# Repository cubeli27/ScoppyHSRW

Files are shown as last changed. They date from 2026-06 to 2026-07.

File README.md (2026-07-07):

# Scoppy 

## Overview
Scoppy is an hardware extension project designed to be compatible with the [original Scopy Project](https://github.com/fhdm-dev/scoppy) developed by fhdm-dev. This repository extends the original Raspberry Pi Pico oscilloscope software by providing custom hardware developed as teaching material for the course Design and Manufacturing of Electronics.

The hardware platform enables students to study and manufacture a complete measurement instrument while using the original Scoppy firmware.

<!-- To-do: Add more photos to the list -->
<p align="center"> 
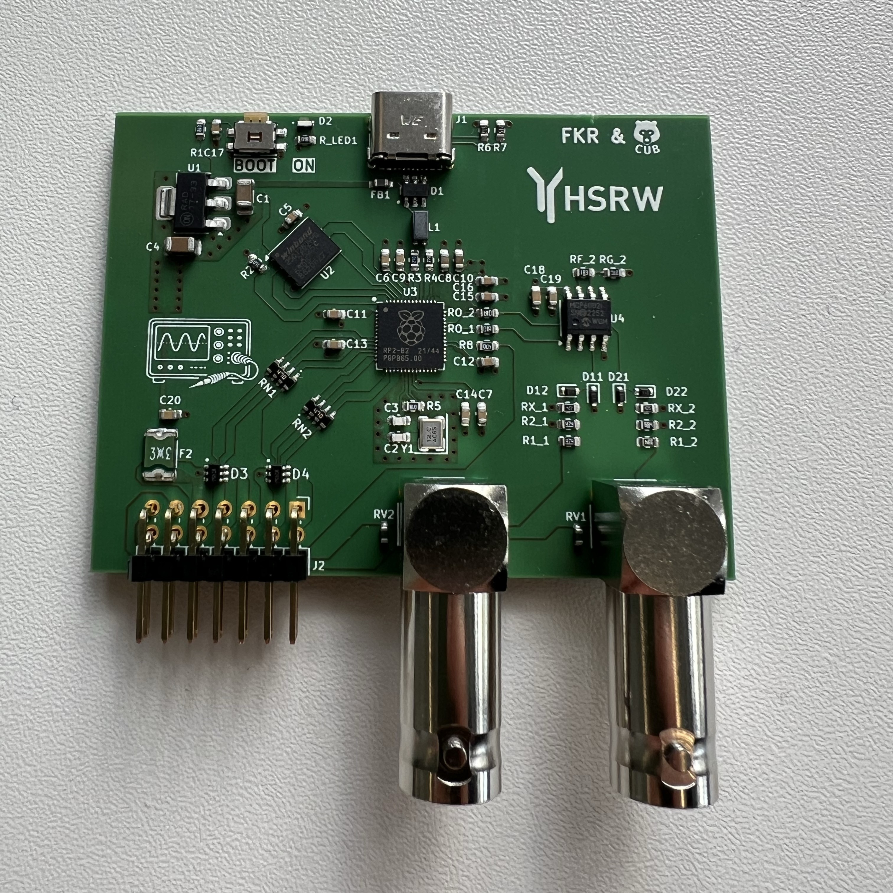
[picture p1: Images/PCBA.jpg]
PCBA
   
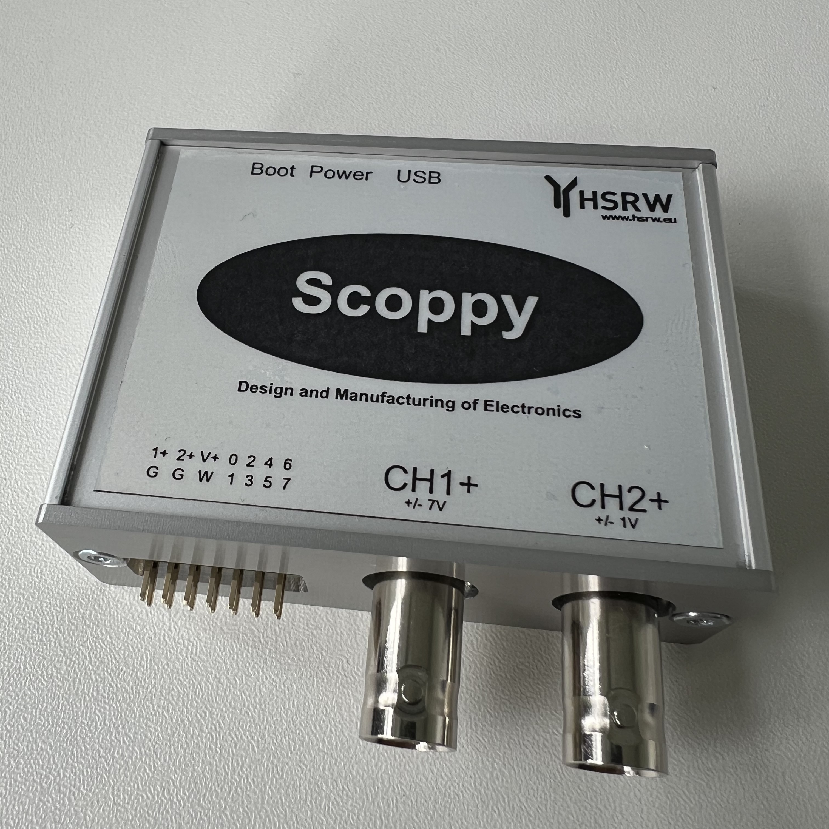
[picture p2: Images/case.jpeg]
   
</p> 

Key Features
- Oscilloscope
- Logic analyzer
- Function generator

---

## Project Structure

| Folder | Description | Contents |
|---|---|---|
| **CAD_files** | Case drawings and pcb | .pdf and .step |
| **ECAD_files** | Contains PCB files | Original design and student template  |
| **Images** | Report relevant snippets | Images |
| **Waveforms** | Waveforms Testing Workspace | .dwf3work |

---

## Testing

Images of Scoppy in action.
<p align="center"> 
  PCBA 
  PCBA 
</p>  

---
## Firmware

Original project can be found at:<br>
[Github](https://github.com/fhdm-dev/scoppy)<br>
[EasyEDA](https://easyeda.com/editor#id=5d5f637d6a8448b59f484372ed679191)<br>
[Website](https://oscilloscope.fhdm.xyz/)  
 
---
## Getting Started

From the [Scoppy Firmware downloads](https://oscilloscope.fhdm.xyz/wiki/firmware-versions) download and flash the **scoppy-pico-v18.uf2** .

---
## Future Work 
C17 capacitor can be omited or not populated. It is the boot push-button debounce capacitor and in some layouts prevents proper booting persumably because the **RUN** pin is left floating so the code starts running while the capacitor is still charging and before **BOOT** pin reaches logic high. 

---
## Acknowledgements

This project would not have been possible without the original Scoppy software created by the fhdm-dev team. Their work provided the foundation that made this hardware implementation possible.
---
## Author

Developed by **cubeli27** with the support of Frank Kremer (FKR)
For questions or collaboration, feel free to reach out. See my contact info in the [profile repo](https://github.com/cubeli27/cubeli27).

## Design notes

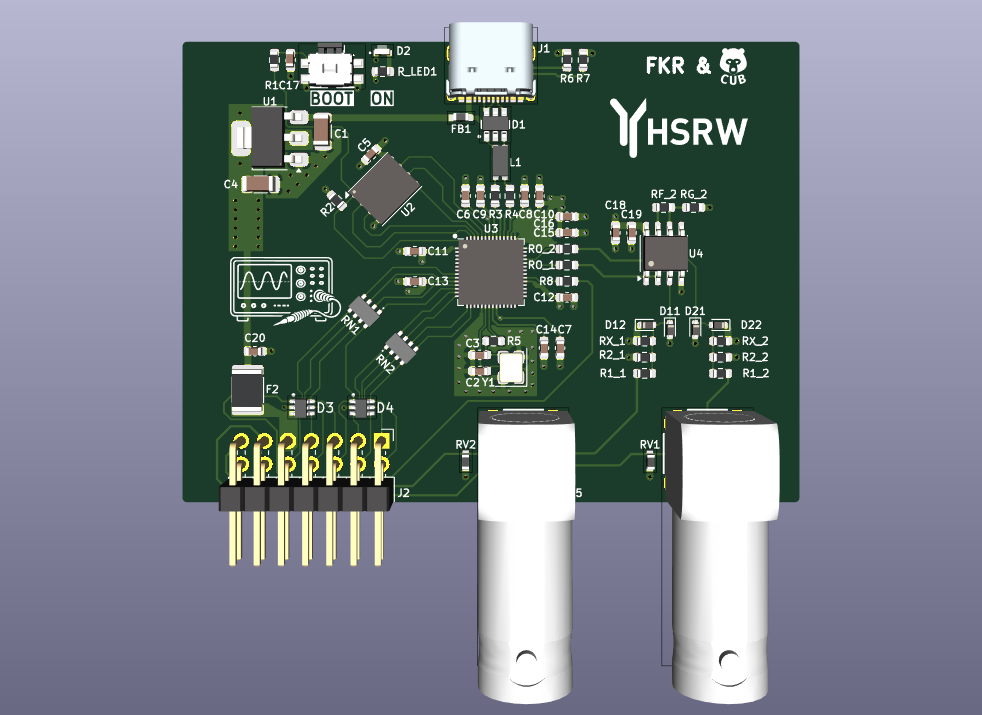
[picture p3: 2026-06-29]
Images/3D Viewer.png

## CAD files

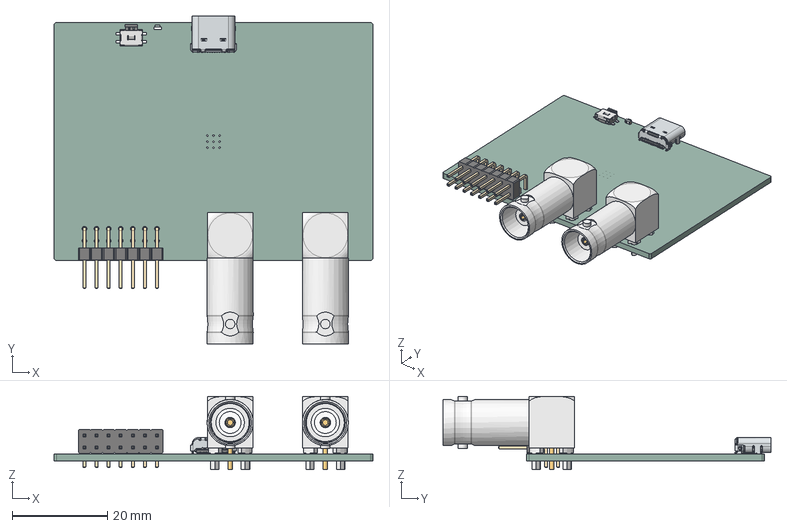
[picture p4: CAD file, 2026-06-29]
CAD_files/scoppy.step
67.0 x 68.9 x 15.4 mm
629722000214_Housing
629722000214_Pin1_Top
629722000214_Pin4_Bottom
629722000214_Pin4_Top x 2
629722000214_Pin1_Bottom
629722000214_Pin3_Bottom
629722000214_Pin3_Top
629722000214_Pin2_Top
629722000214_Pin2_Bottom
629722000214_Pin1_Top_mir
629722000214_Pin1_Bottom_mir
629722000214_Pin2_Top_mir
629722000214_Pin2_Bottom_mir
629722000214_Pin3_Top_mir
629722000214_Pin3_Bottom_mir
629722000214_Pin4_Bottom_mir
629722000214_Shielding2
629722000214_Shielding
PinHeader_2x07_P2.54mm_Horizontal
60711002241501_Body x 2
60711002241501_Cover x 2
60711002241501_housing x 2
60711002241501_insulator x 2
60711002241501_insulator_2 x 2
60711002241501_Lok_Ring x 2
60711002241501_Pin x 2
60711002241501_Pin_2 x 2
frame
pins x 4
stem
cover
Pins
Dome
scoppy_PCB

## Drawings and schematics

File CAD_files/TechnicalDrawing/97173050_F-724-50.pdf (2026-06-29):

5

8

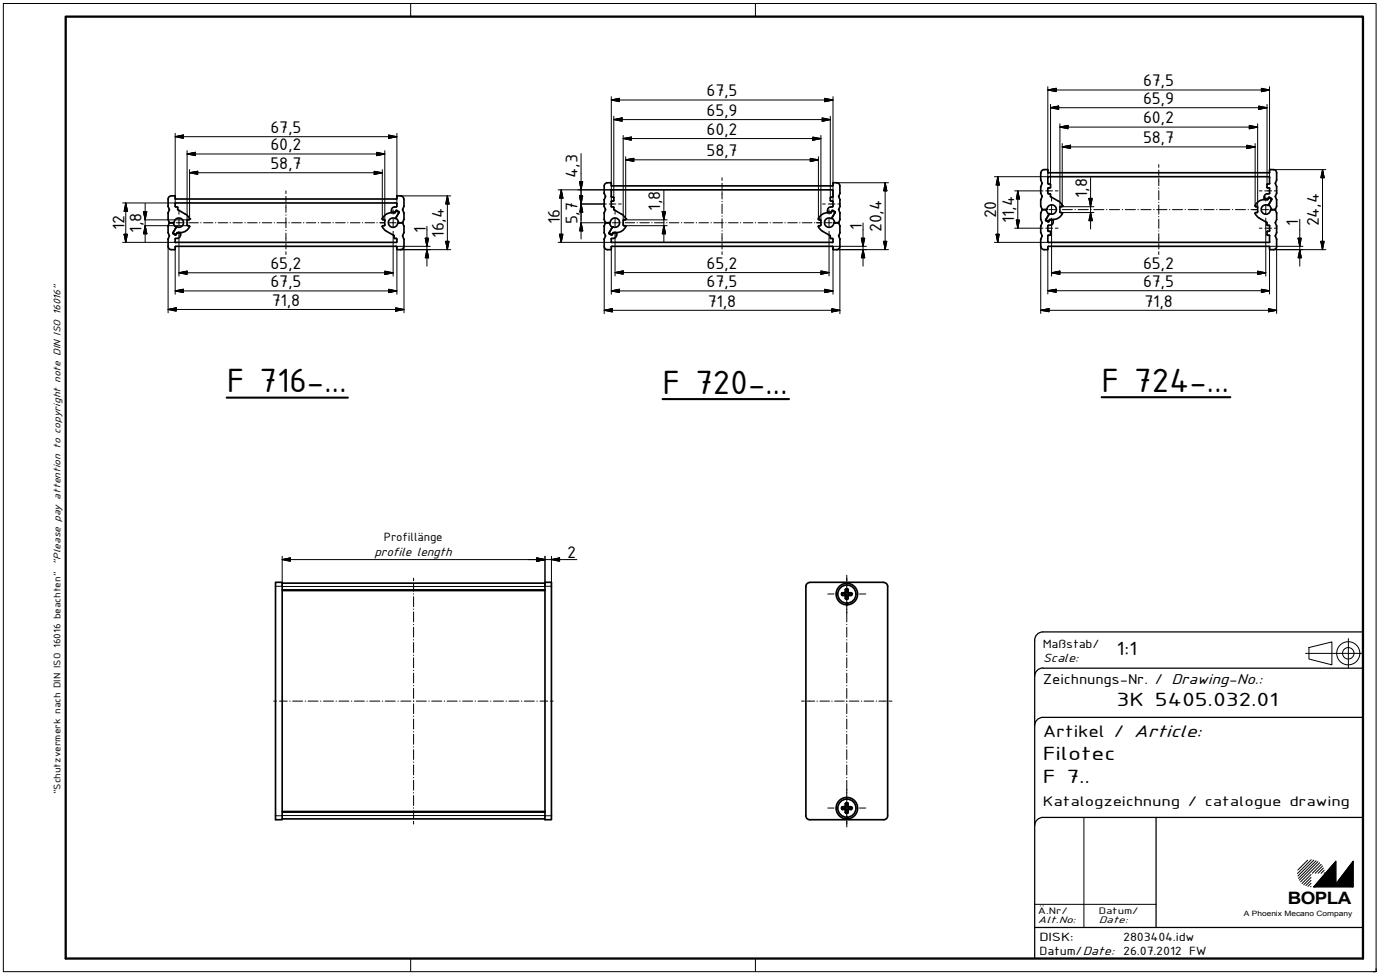
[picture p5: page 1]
tik; DIS; K: Filo; eic; 7.. Katalo; win; fil

"Schutzvermerk nach DIN ISO 16016 beachten" "Please pay attention to copyright note DIN ISO 16016"

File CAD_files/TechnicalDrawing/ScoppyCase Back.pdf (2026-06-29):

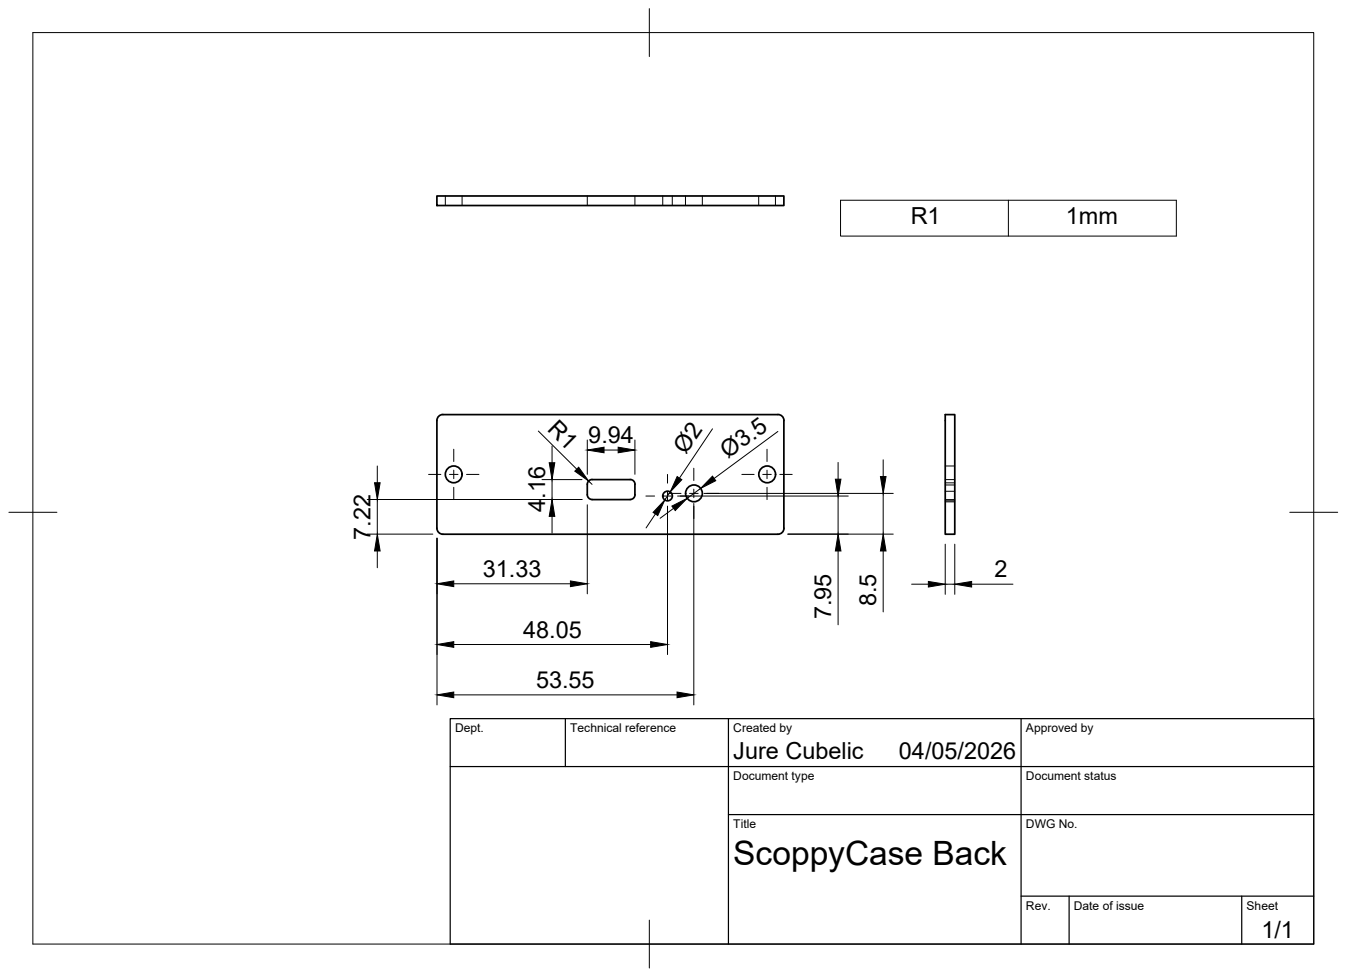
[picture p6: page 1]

Dept. | Technical reference | Created by Jure Cubelic 04/05/2026 | Approved by

Document type | Document status

Title ScoppyCase Back | DWG No.

Rev. | Date of issue | Sheet 1/1

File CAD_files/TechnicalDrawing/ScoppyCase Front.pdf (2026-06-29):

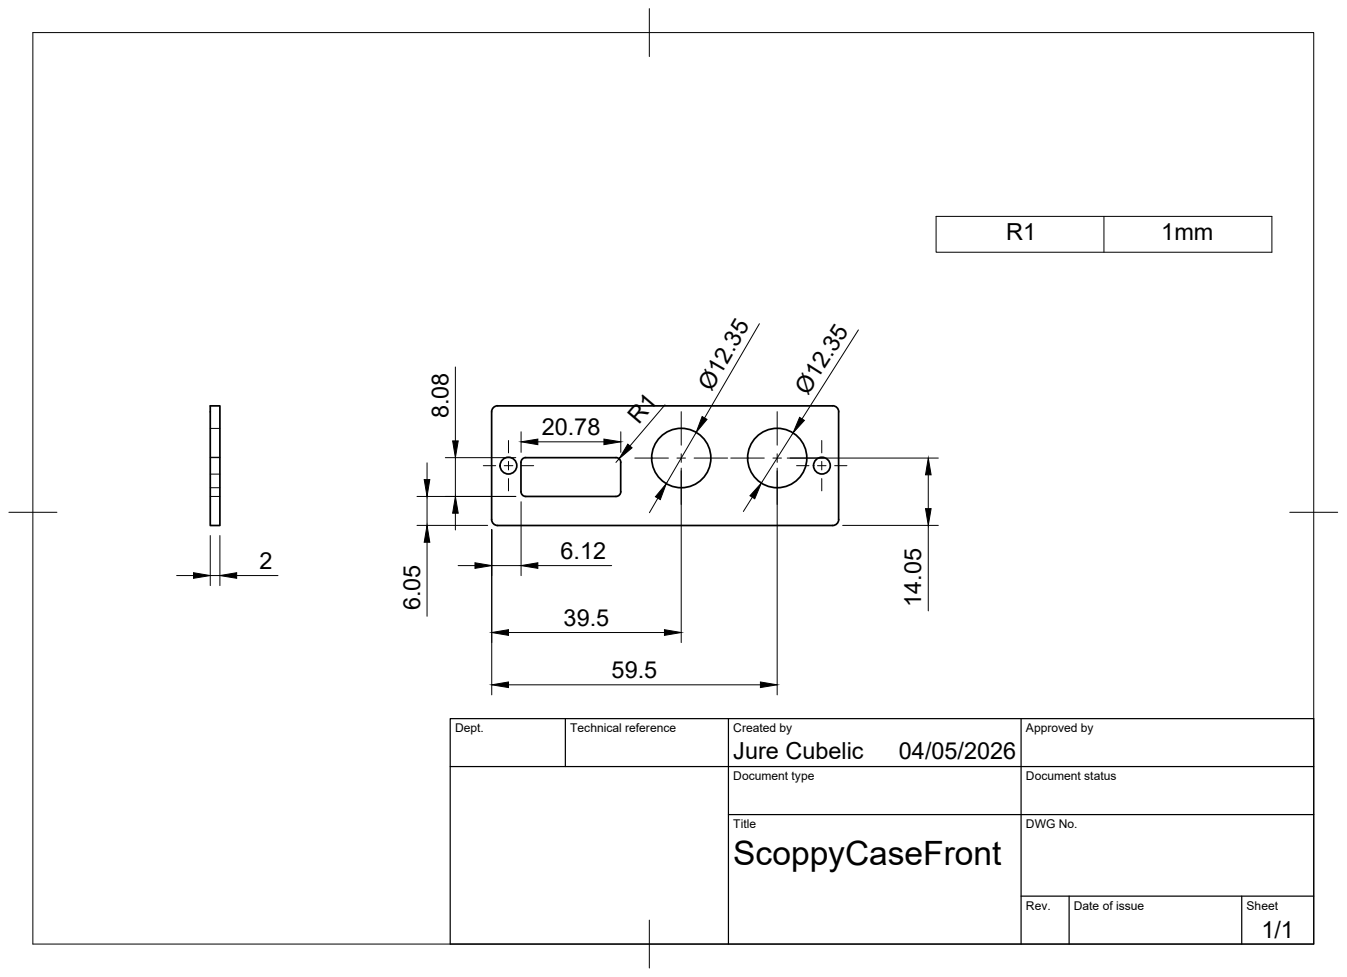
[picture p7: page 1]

Dept. | Technical reference | Created by Jure Cubelic 04/05/2026 | Approved by

Document type | Document status

Title ScoppyCaseFront | DWG No.

Rev. | Date of issue | Sheet 1/1

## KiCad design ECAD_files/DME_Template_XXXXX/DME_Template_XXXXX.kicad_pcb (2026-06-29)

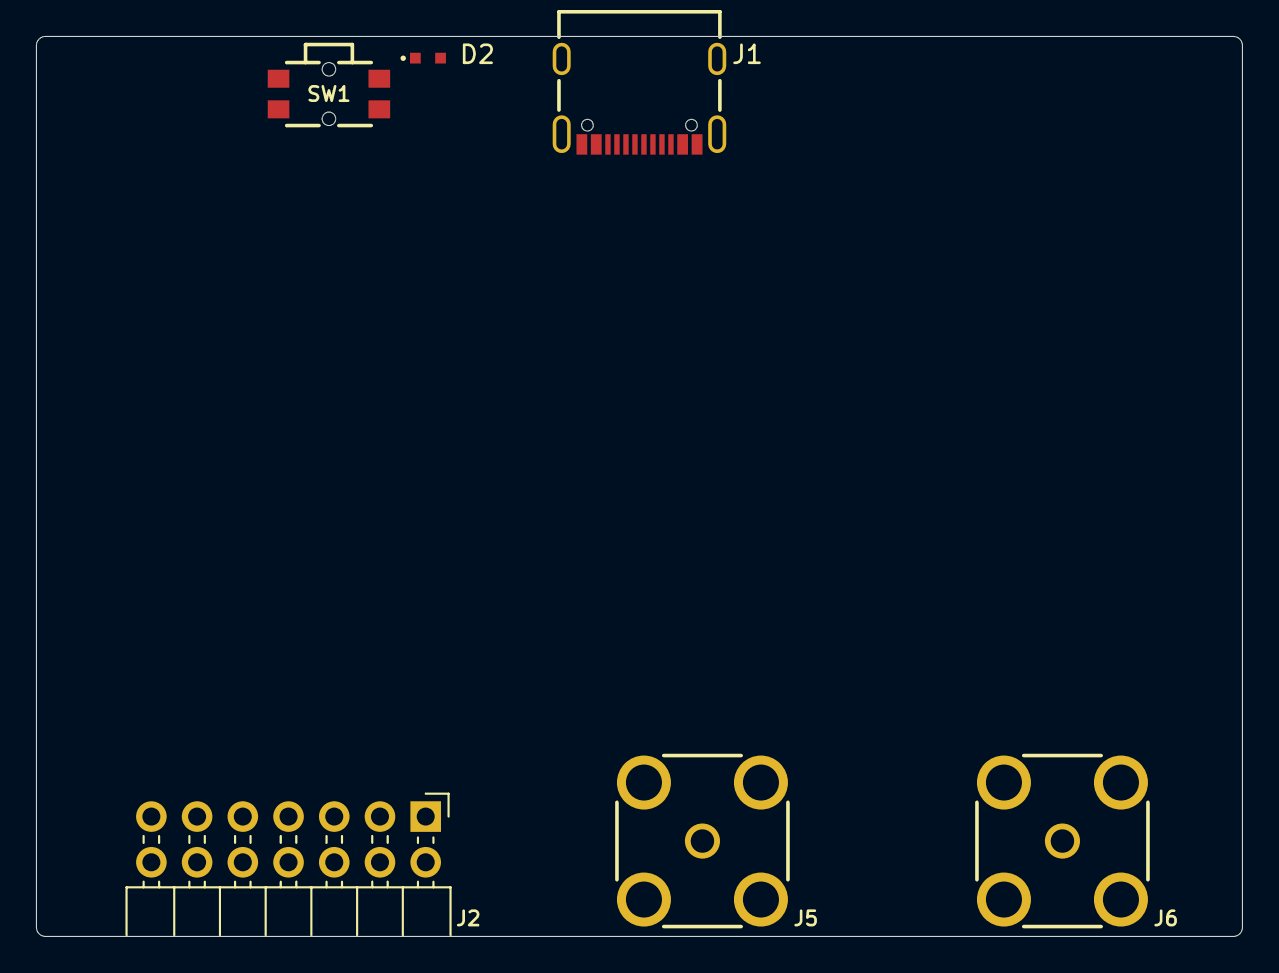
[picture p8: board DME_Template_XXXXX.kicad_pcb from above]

Board: 4 copper layers, 67.0 x 50.0 mm, 6 parts (0 on the bottom side), 7 nets, no tracks yet.

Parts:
D2: Bright Green, 2V, 140°; WL-SMSW_0603_L1.6W0.98H0.8
J1: 629722000214
J2: Conn_02x07_Odd_Even; PinHeader_2x07_P2.54mm_Horizontal
J5, J6: 60711002241501
SW1: 436351045816

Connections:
/Analog/CH1+: J2.13, J5.1 (Signal)
/Analog/CH2+: J2.11, J6.1 (Signal)
/Digital/~USB_BOOT: SW1.B1, SW1.B2
/Power/unprotectedD+: J1.A6 (D+1), J1.B6 (D+2)
/Power/unprotectedD-: J1.A7 (D-1), J1.B7 (D-2)
GND: D2.1 (K), J1.A1/B12 (GND), J1.A12/B1 (GND), J1.Shell (Shield), J2.12, J2.14, J5.2 (GND), J5.3 (GND), J5.4 (GND), J5.5 (GND), J6.2 (GND), J6.3 (GND), J6.4 (GND), J6.5 (GND), SW1.A1, SW1.A2
VBUS: J1.A4/B9 (VBUS), J1.A9/B4 (VBUS)

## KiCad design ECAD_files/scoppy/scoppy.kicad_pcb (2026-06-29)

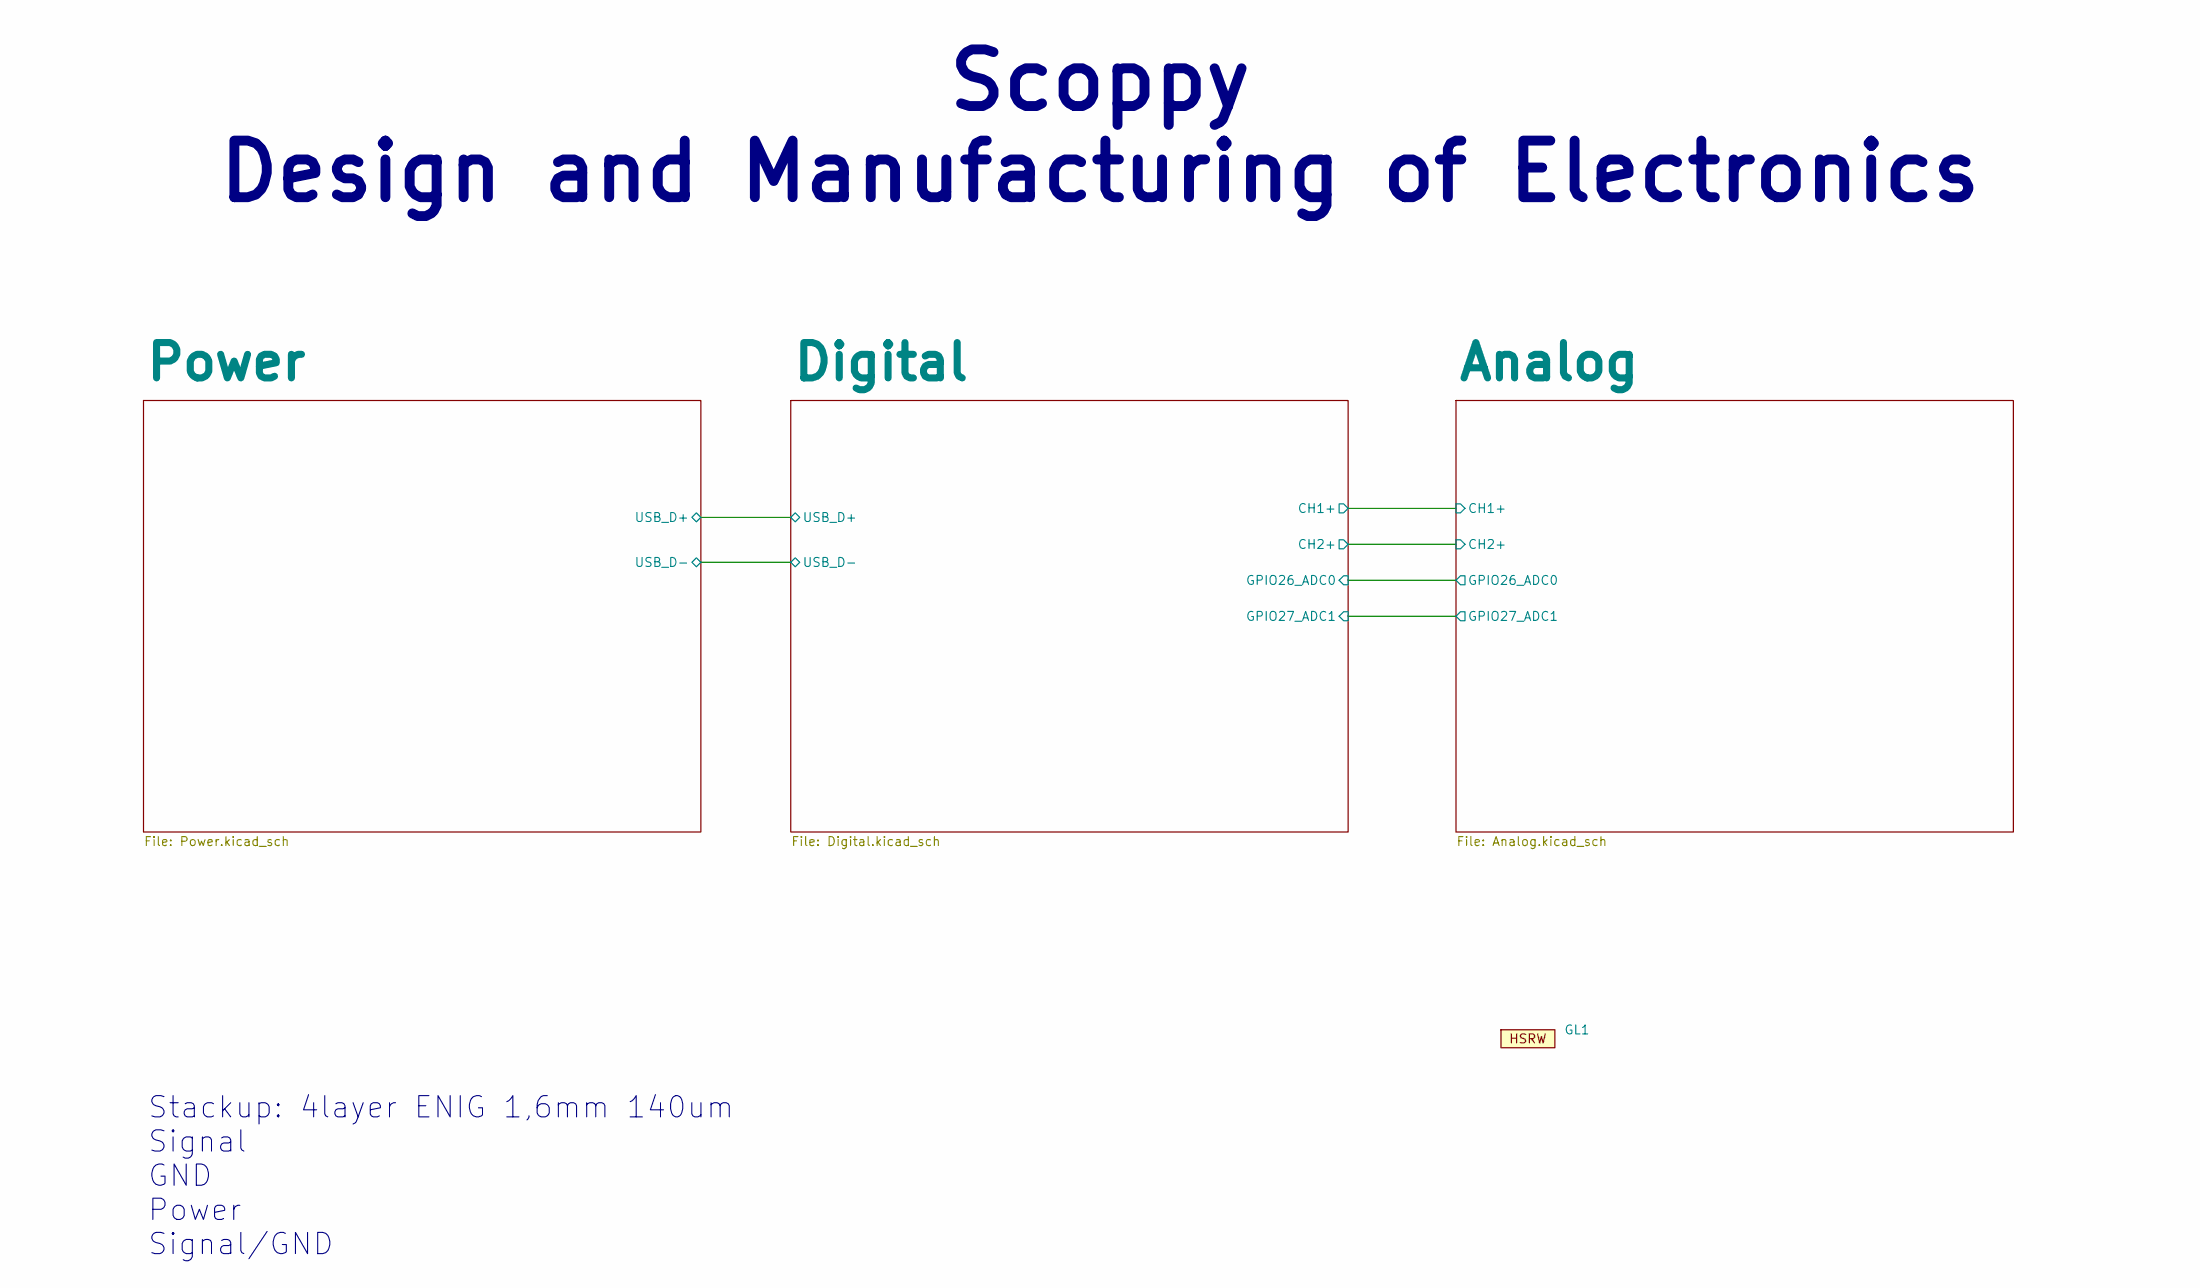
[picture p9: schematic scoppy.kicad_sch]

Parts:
GL1: hsrw

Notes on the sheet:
Stackup: 4layer ENIG 1,6mm 140um Signal GND Power Signal/GND
Scoppy Design and Manufacturing of Electronics

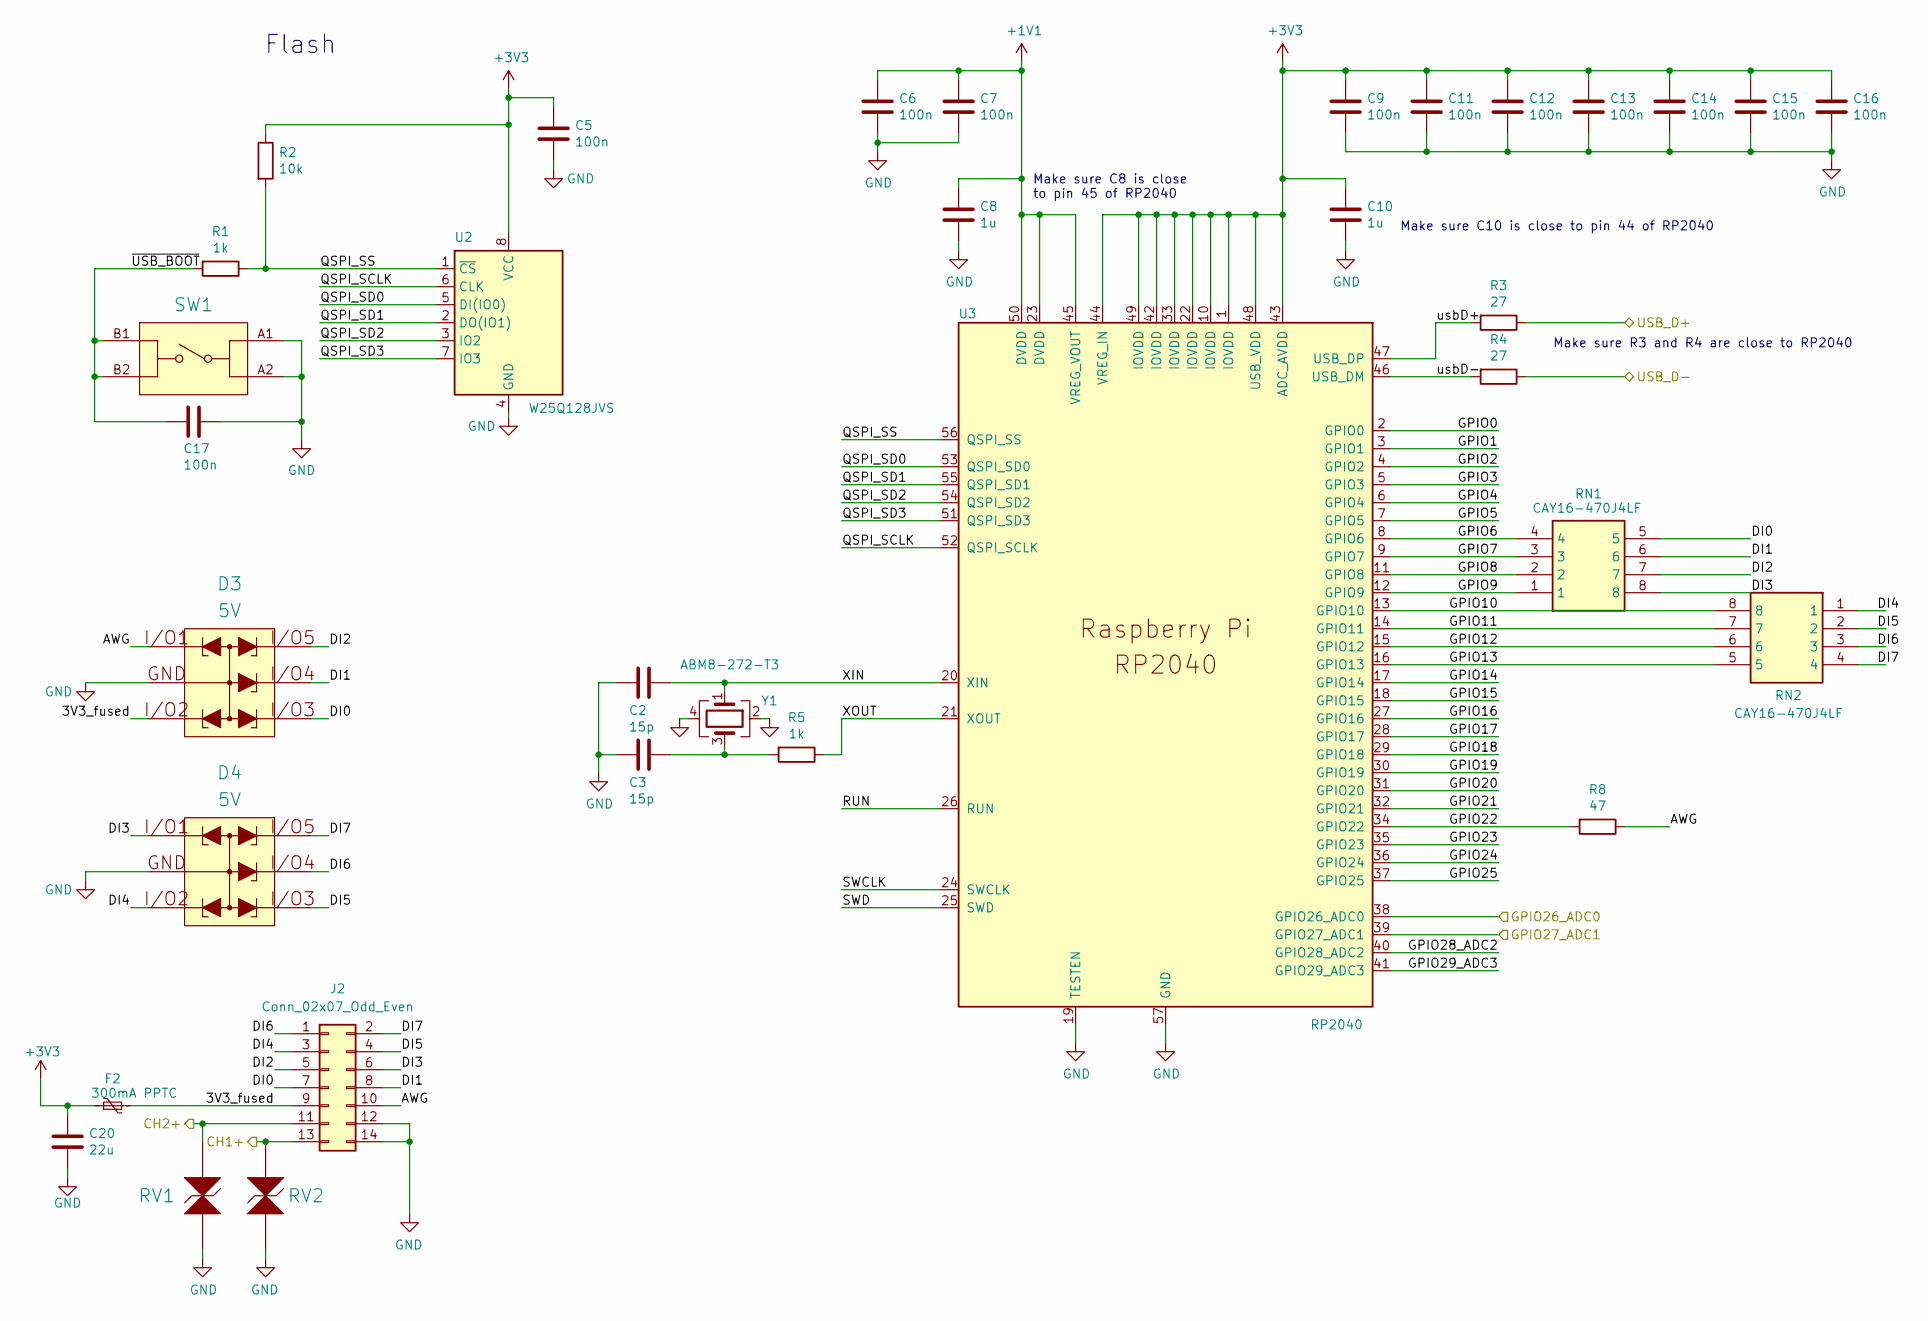
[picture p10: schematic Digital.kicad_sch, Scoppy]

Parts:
C2, C3: 15p; C_0603_1608Metric
C5, C6, C7, C9, C11, C12, C13, C14, C15, C16, C17: 100n; C_0603_1608Metric
C8, C10: 1u; C_0603_1608Metric
C20: 22u; C_0603_1608Metric
D3, D4: 5V; WE-TVS_SC70-6L; Manufacturer Part Number 82402375
F2: 300mA PPTC; Fuse_1812_4532Metric
J2: Conn_02x07_Odd_Even; PinHeader_2x07_P2.54mm_Horizontal
R1, R5: 1k; R_0603_1608Metric
R2: 10k; R_0603_1608Metric
R3, R4: 27; R_0603_1608Metric
R8: 47; R_0603_1608Metric
RN1, RN2: CAY16-470J4LF; CAY16470J4LF; Mouser Part Number 652-CAY16-470J4LF
RV1, RV2: 12VDC, 5pF; WE-VE_0603; Clamping Voltage 80V; ESD Voltage 15kV; Manufacturer Part Number 82356120050
SW1: 436351045816; Rated Voltage 12VDC; Manufacturer Part Number 436351045816
U2: W25Q128JVS; WSON-8-1EP_6x5mm_P1.27mm_EP3.4x4.3mm
U3: RP2040; RP2040-QFN-56
Y1: ABM8-272-T3; Crystal_SMD_3225-4Pin_3.2x2.5mm

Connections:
+1V1: C6.1, C7.1, C8.1, U3.23 (DVDD), U3.45 (VREG_VOUT), U3.50 (DVDD)
+3V3: C5.1, C9.1, C10.1, C11.1, C12.1, C13.1, C14.1, C15.1, C16.1, C20.1, F2.2, R2.1, U2.8 (VCC), U3.1 (IOVDD), U3.10 (IOVDD), U3.22 (IOVDD), U3.33 (IOVDD), U3.42 (IOVDD), U3.43 (ADC_AVDD), U3.44 (VREG_IN), U3.48 (USB_VDD), U3.49 (IOVDD); also elsewhere on the board
/Analog/CH1+: J2.13, RV2.2; also elsewhere on the board
/Analog/CH2+: J2.11, RV1.2; also elsewhere on the board
/Analog/GPIO26_ADC0: U3.38 (GPIO26_ADC0); also elsewhere on the board
/Analog/GPIO27_ADC1: U3.39 (GPIO27_ADC1); also elsewhere on the board
/Digital/3V3_fused: D3.3 (I/O_2), F2.1, J2.9
/Digital/AWG: D3.1 (I/O_1), J2.10, R8.1
/Digital/DI0: D3.4 (I/O_3), J2.7, RN1.5
/Digital/DI1: D3.5 (I/O_4), J2.8, RN1.6
/Digital/DI2: D3.6 (I/O_5), J2.5, RN1.7
/Digital/DI3: D4.1 (I/O_1), J2.6, RN1.8
/Digital/DI4: D4.3 (I/O_2), J2.3, RN2.1
/Digital/DI5: D4.4 (I/O_3), J2.4, RN2.2
/Digital/DI6: D4.5 (I/O_4), J2.1, RN2.3
/Digital/DI7: D4.6 (I/O_5), J2.2, RN2.4
/Digital/GPIO0: U3.2 (GPIO0)
/Digital/GPIO1: U3.3 (GPIO1)
/Digital/GPIO2: U3.4 (GPIO2)
/Digital/GPIO3: U3.5 (GPIO3)
/Digital/GPIO4: U3.6 (GPIO4)
/Digital/GPIO5: U3.7 (GPIO5)
/Digital/GPIO6: RN1.4, U3.8 (GPIO6)
/Digital/GPIO7: RN1.3, U3.9 (GPIO7)
/Digital/GPIO8: RN1.2, U3.11 (GPIO8)
/Digital/GPIO9: RN1.1, U3.12 (GPIO9)
/Digital/GPIO10: RN2.8, U3.13 (GPIO10)
/Digital/GPIO11: RN2.7, U3.14 (GPIO11)
/Digital/GPIO12: RN2.6, U3.15 (GPIO12)
/Digital/GPIO13: RN2.5, U3.16 (GPIO13)
/Digital/GPIO14: U3.17 (GPIO14)
/Digital/GPIO15: U3.18 (GPIO15)
/Digital/GPIO16: U3.27 (GPIO16)
/Digital/GPIO17: U3.28 (GPIO17)
/Digital/GPIO18: U3.29 (GPIO18)
/Digital/GPIO19: U3.30 (GPIO19)
/Digital/GPIO20: U3.31 (GPIO20)
/Digital/GPIO21: U3.32 (GPIO21)
/Digital/GPIO22: R8.2, U3.34 (GPIO22)
/Digital/GPIO23: U3.35 (GPIO23)
/Digital/GPIO24: U3.36 (GPIO24)
/Digital/GPIO25: U3.37 (GPIO25)
/Digital/GPIO28_ADC2: U3.40 (GPIO28_ADC2)
/Digital/GPIO29_ADC3: U3.41 (GPIO29_ADC3)
/Digital/QSPI_SCLK: U2.6 (CLK), U3.52 (QSPI_SCLK)
/Digital/QSPI_SD0: U2.5 (DI(IO0)), U3.53 (QSPI_SD0)
/Digital/QSPI_SD1: U2.2 (DO(IO1)), U3.55 (QSPI_SD1)
/Digital/QSPI_SD2: U2.3 (IO2), U3.54 (QSPI_SD2)
/Digital/QSPI_SD3: U2.7 (IO3), U3.51 (QSPI_SD3)
/Digital/QSPI_SS: R1.1, R2.2, U2.1 (~CS), U3.56 (QSPI_SS)
/Digital/RUN: U3.26 (RUN)
/Digital/SWCLK: U3.24 (SWCLK)
/Digital/SWD: U3.25 (SWD)
/Digital/USB_D+: R3.1; also elsewhere on the board
/Digital/USB_D-: R4.1; also elsewhere on the board
/Digital/XIN: C2.1, U3.20 (XIN), Y1.1
/Digital/XOUT: R5.1, U3.21 (XOUT)
/Digital/usbD+: R3.2, U3.47 (USB_DP)
/Digital/usbD-: R4.2, U3.46 (USB_DM)
/Digital/~USB_BOOT: C17.1, R1.2, SW1.B1, SW1.B2
GND: C2.2, C3.2, C5.2, C6.2, C7.2, C8.2, C9.2, C10.2, C11.2, C12.2, C13.2, C14.2, C15.2, C16.2, C17.2, C20.2, D3.2 (GND), D4.2 (GND), J2.12, J2.14, RV1.1, RV2.1, SW1.A1, SW1.A2, U2.4 (GND), U3.19 (TESTEN), U3.57 (GND), Y1.2, Y1.4; also elsewhere on the board
unnamed: C3.1, R5.2, Y1.3

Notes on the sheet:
Make sure C8 is close to pin 45 of RP2040
Flash
Make sure R3 and R4 are close to RP2040
Make sure C10 is close to pin 44 of RP2040

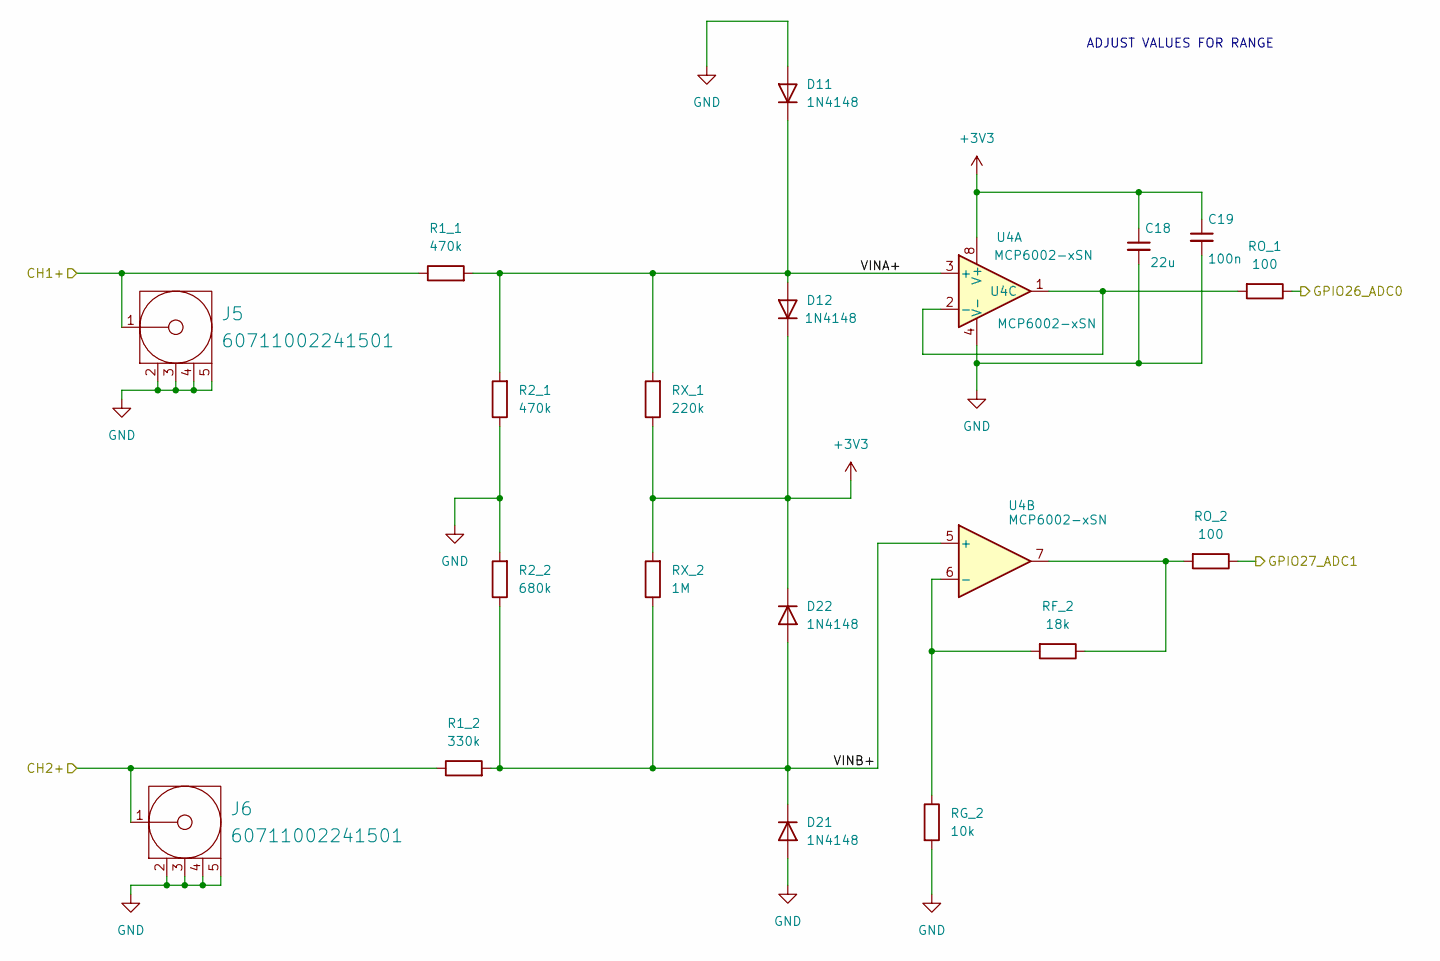
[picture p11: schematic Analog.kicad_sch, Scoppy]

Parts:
C18: 22u; C_0603_1608Metric
C19: 100n; C_0603_1608Metric
D11, D12, D21, D22: 1N4148; D_SOD-523
J5, J6: 60711002241501; Manufacturer Part Number 60711002241501
R1_1, R2_1: 470k; R_0603_1608Metric
R1_2: 330k; R_0603_1608Metric
R2_2: 680k; R_0603_1608Metric
RF_2: 18k; R_0603_1608Metric
RG_2: 10k; R_0603_1608Metric
RO_1, RO_2: 100; R_0603_1608Metric
RX_1: 220k; R_0603_1608Metric
RX_2: 1M; R_0603_1608Metric
U4: MCP6002-xSN; SOIC-8_3.9x4.9mm_P1.27mm

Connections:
+3V3: C18.1, C19.1, D12.1 (K), D22.1 (K), RX_1.1, RX_2.2, U4.8 (V+); also elsewhere on the board
/Analog/CH1+: J5.1 (Signal), R1_1.1; also elsewhere on the board
/Analog/CH2+: J6.1 (Signal), R1_2.1; also elsewhere on the board
/Analog/GPIO26_ADC0: RO_1.1; also elsewhere on the board
/Analog/GPIO27_ADC1: RO_2.1; also elsewhere on the board
/Analog/VINA+: D11.1 (K), D12.2 (A), R1_1.2, R2_1.2, RX_1.2, U4.3 (+)
/Analog/VINB+: D21.1 (K), D22.2 (A), R1_2.2, R2_2.1, RX_2.1, U4.5 (+)
GND: C18.2, C19.2, D11.2 (A), D21.2 (A), J5.2 (GND), J5.3 (GND), J5.4 (GND), J5.5 (GND), J6.2 (GND), J6.3 (GND), J6.4 (GND), J6.5 (GND), R2_1.1, R2_2.2, RG_2.2, U4.4 (V-); also elsewhere on the board
unnamed: RF_2.1, RO_2.2, U4.7
unnamed: RO_1.2, U4.1, U4.2 (-)
unnamed: RF_2.2, RG_2.1, U4.6 (-)

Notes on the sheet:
ADJUST VALUES FOR RANGE

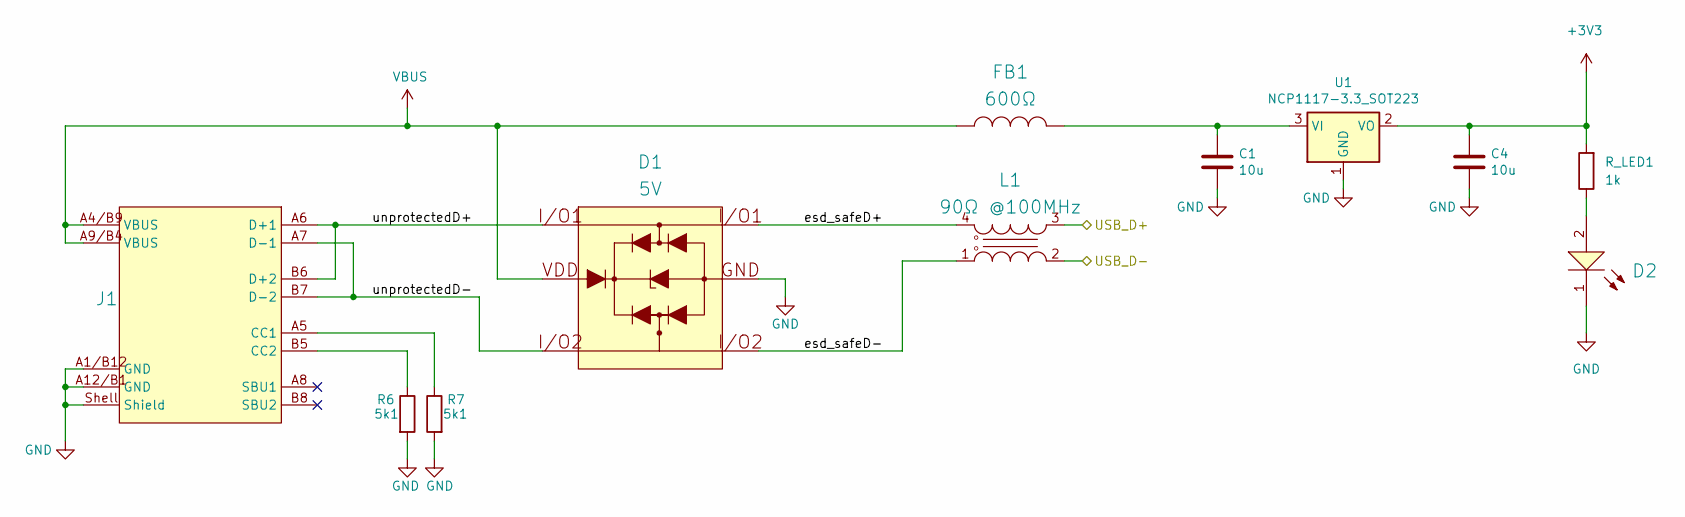
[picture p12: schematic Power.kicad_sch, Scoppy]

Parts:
C1, C4: 10u; C_1206_3216Metric
D1: 5V; WE-TVS_SOT23-6L; Manufacturer Part Number 82400102
D2: Bright Green, 2V, 140°; WL-SMSW_0603_L1.6W0.98H0.8; Forward Voltage 2V; Manufacturer Part Number 155060VS75300
FB1: 600Ω; WE-CBF_0603_L1.6W0.8H0.8_HC; Manufacturer Part Number 742792651
J1: 629722000214; Working Voltage 48V (DC); Manufacturer Part Number 629722000214
L1: 90Ω @100MHz; WE-CNSW_1206; Rated Voltage 50V; Manufacturer Part Number 744232090
R6, R7: 5k1; R_0603_1608Metric
R_LED1: 1k; R_0603_1608Metric
U1: NCP1117-3.3_SOT223; SOT-223-3_TabPin2

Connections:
+3V3: C4.1, R_LED1.2, U1.2 (VO); also elsewhere on the board
/Digital/USB_D+: L1.3; also elsewhere on the board
/Digital/USB_D-: L1.2; also elsewhere on the board
/Power/esd_safeD+: D1.1 (I/O_1), L1.4
/Power/esd_safeD-: D1.3 (I/O_2), L1.1
/Power/unprotectedD+: D1.6 (I/O_1), J1.A6 (D+1), J1.B6 (D+2)
/Power/unprotectedD-: D1.4 (I/O_2), J1.A7 (D-1), J1.B7 (D-2)
GND: C1.2, C4.2, D1.2 (GND), D2.1 (K), J1.A1/B12 (GND), J1.A12/B1 (GND), J1.Shell (Shield), R6.2, R7.2, U1.1 (GND); also elsewhere on the board
unnamed: D2.2 (A), R_LED1.1
unnamed: J1.A5 (CC1), R7.1
unnamed: J1.B5 (CC2), R6.1
unnamed: C1.1, FB1.2, U1.3 (VI)
VBUS: D1.5 (VDD), FB1.1, J1.A4/B9 (VBUS), J1.A9/B4 (VBUS)

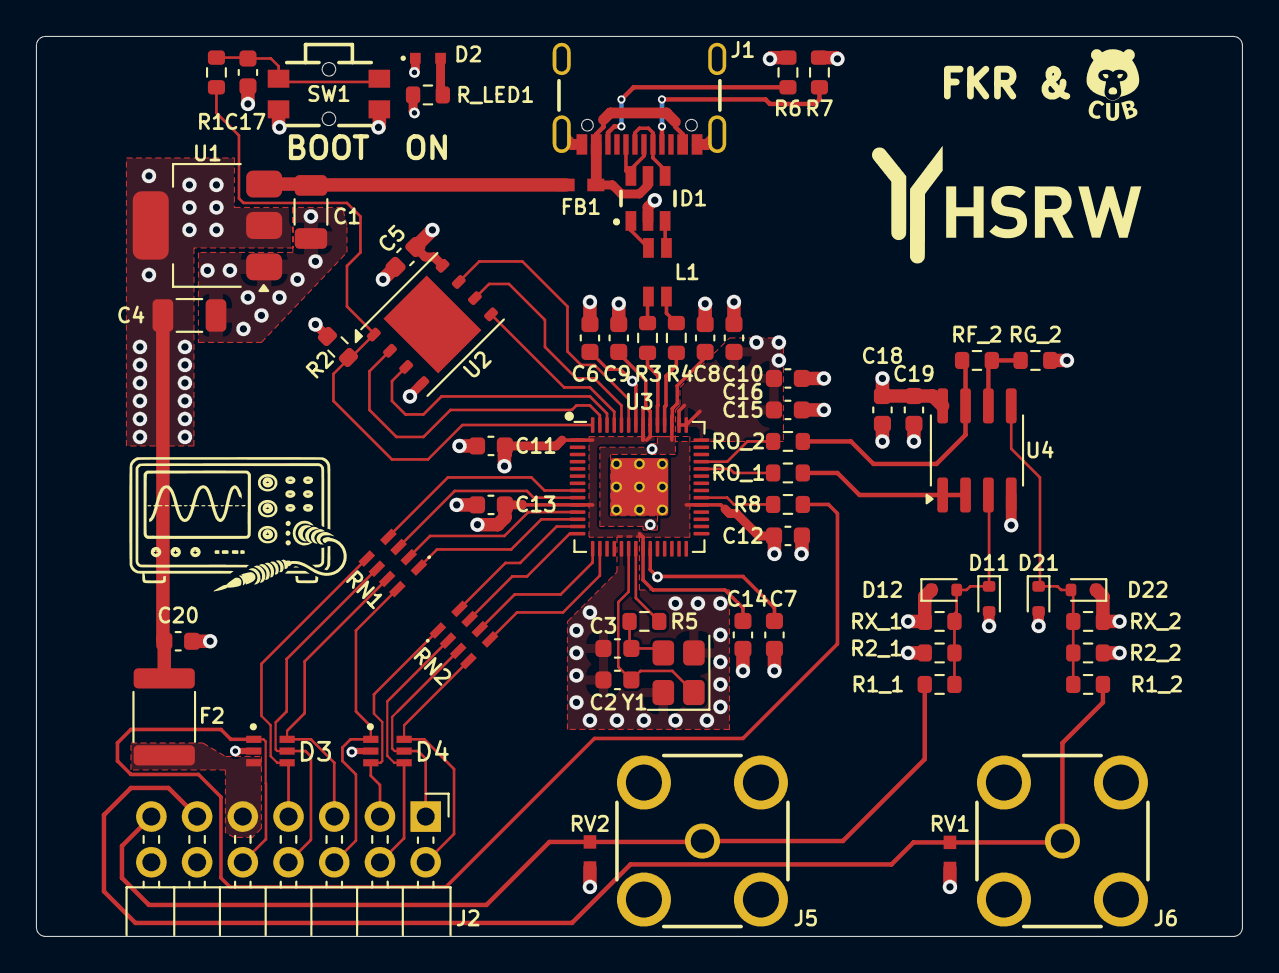
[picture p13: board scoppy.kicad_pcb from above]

Board: 4 copper layers, 67.0 x 50.0 mm, 65 parts (0 on the bottom side), 54 nets.
